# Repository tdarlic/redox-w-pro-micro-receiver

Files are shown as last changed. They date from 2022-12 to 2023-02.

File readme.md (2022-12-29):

# [Redox](https://github.com/mattdibi/redox-keyboard) W Pro Micro receiver

The original Redox keyboard is using receiver that consists from the Arduino Pro Micro board and custom made "shield"
that is used to put few leds and a YJ-14015 module (Core51822B clone).

This PCB uses the on board copper connection to plug directly into the computer.
 
The rest of the board can be used the same way, there is a programming port for YJ-14015 module.

## Versions

### Full version [main branch]
This is single sided PCB with few test pads on the bottom
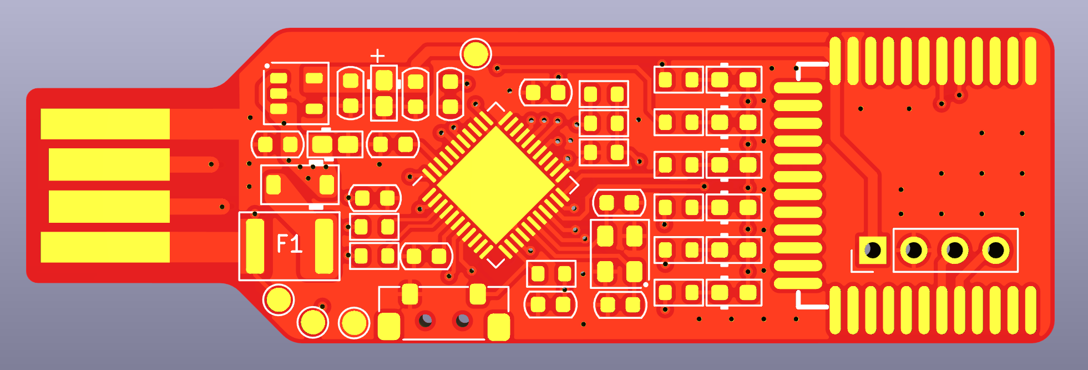
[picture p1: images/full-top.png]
Full board top side

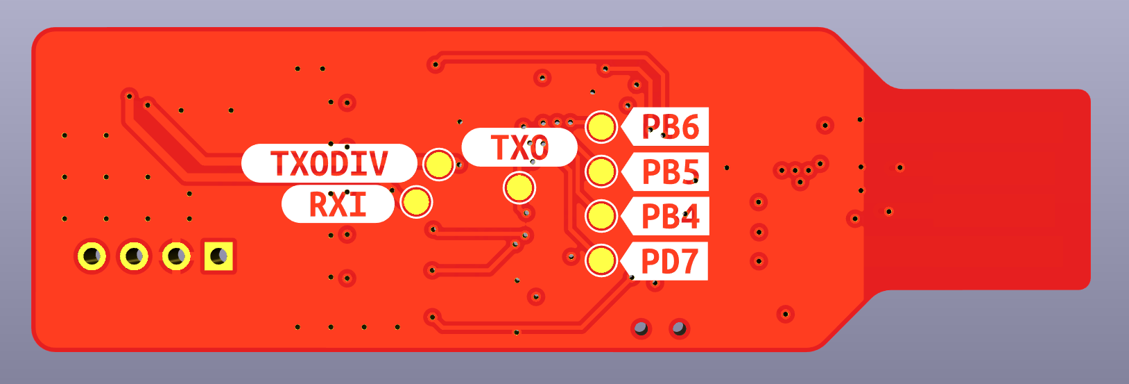
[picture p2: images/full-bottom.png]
Full board bottom side


### Mini version [mini branch]
This is double sided PCB with YJ-14015 on the bottom together with some test pads
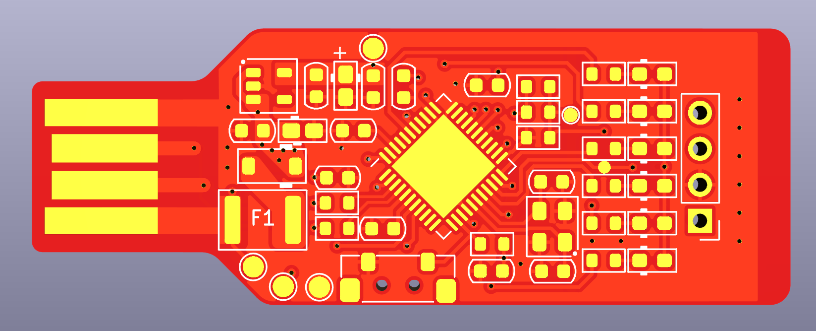
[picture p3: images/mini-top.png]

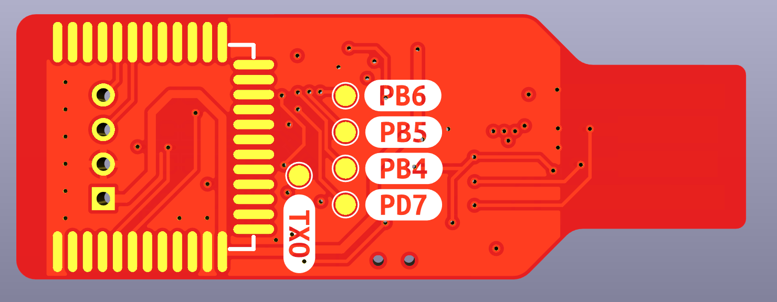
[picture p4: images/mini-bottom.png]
Full board bottom side


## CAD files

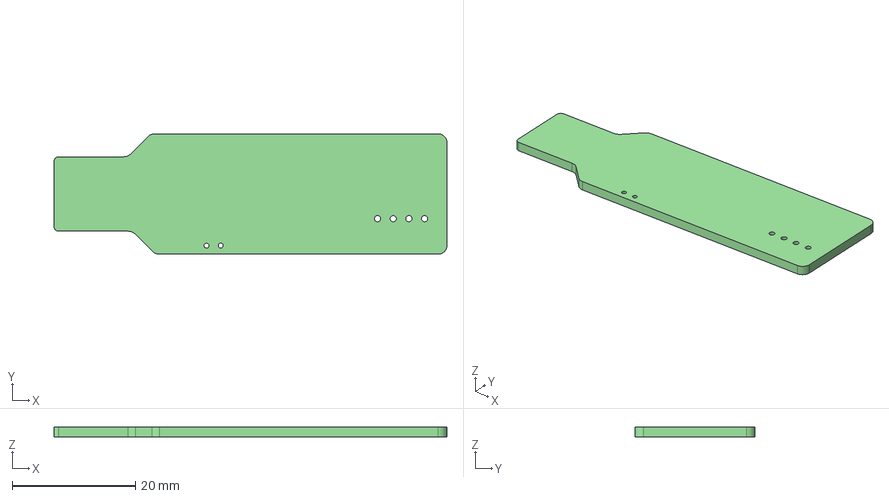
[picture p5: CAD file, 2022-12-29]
3d/pro-micro-receiver.step
63.7 x 19.5 x 1.61 mm

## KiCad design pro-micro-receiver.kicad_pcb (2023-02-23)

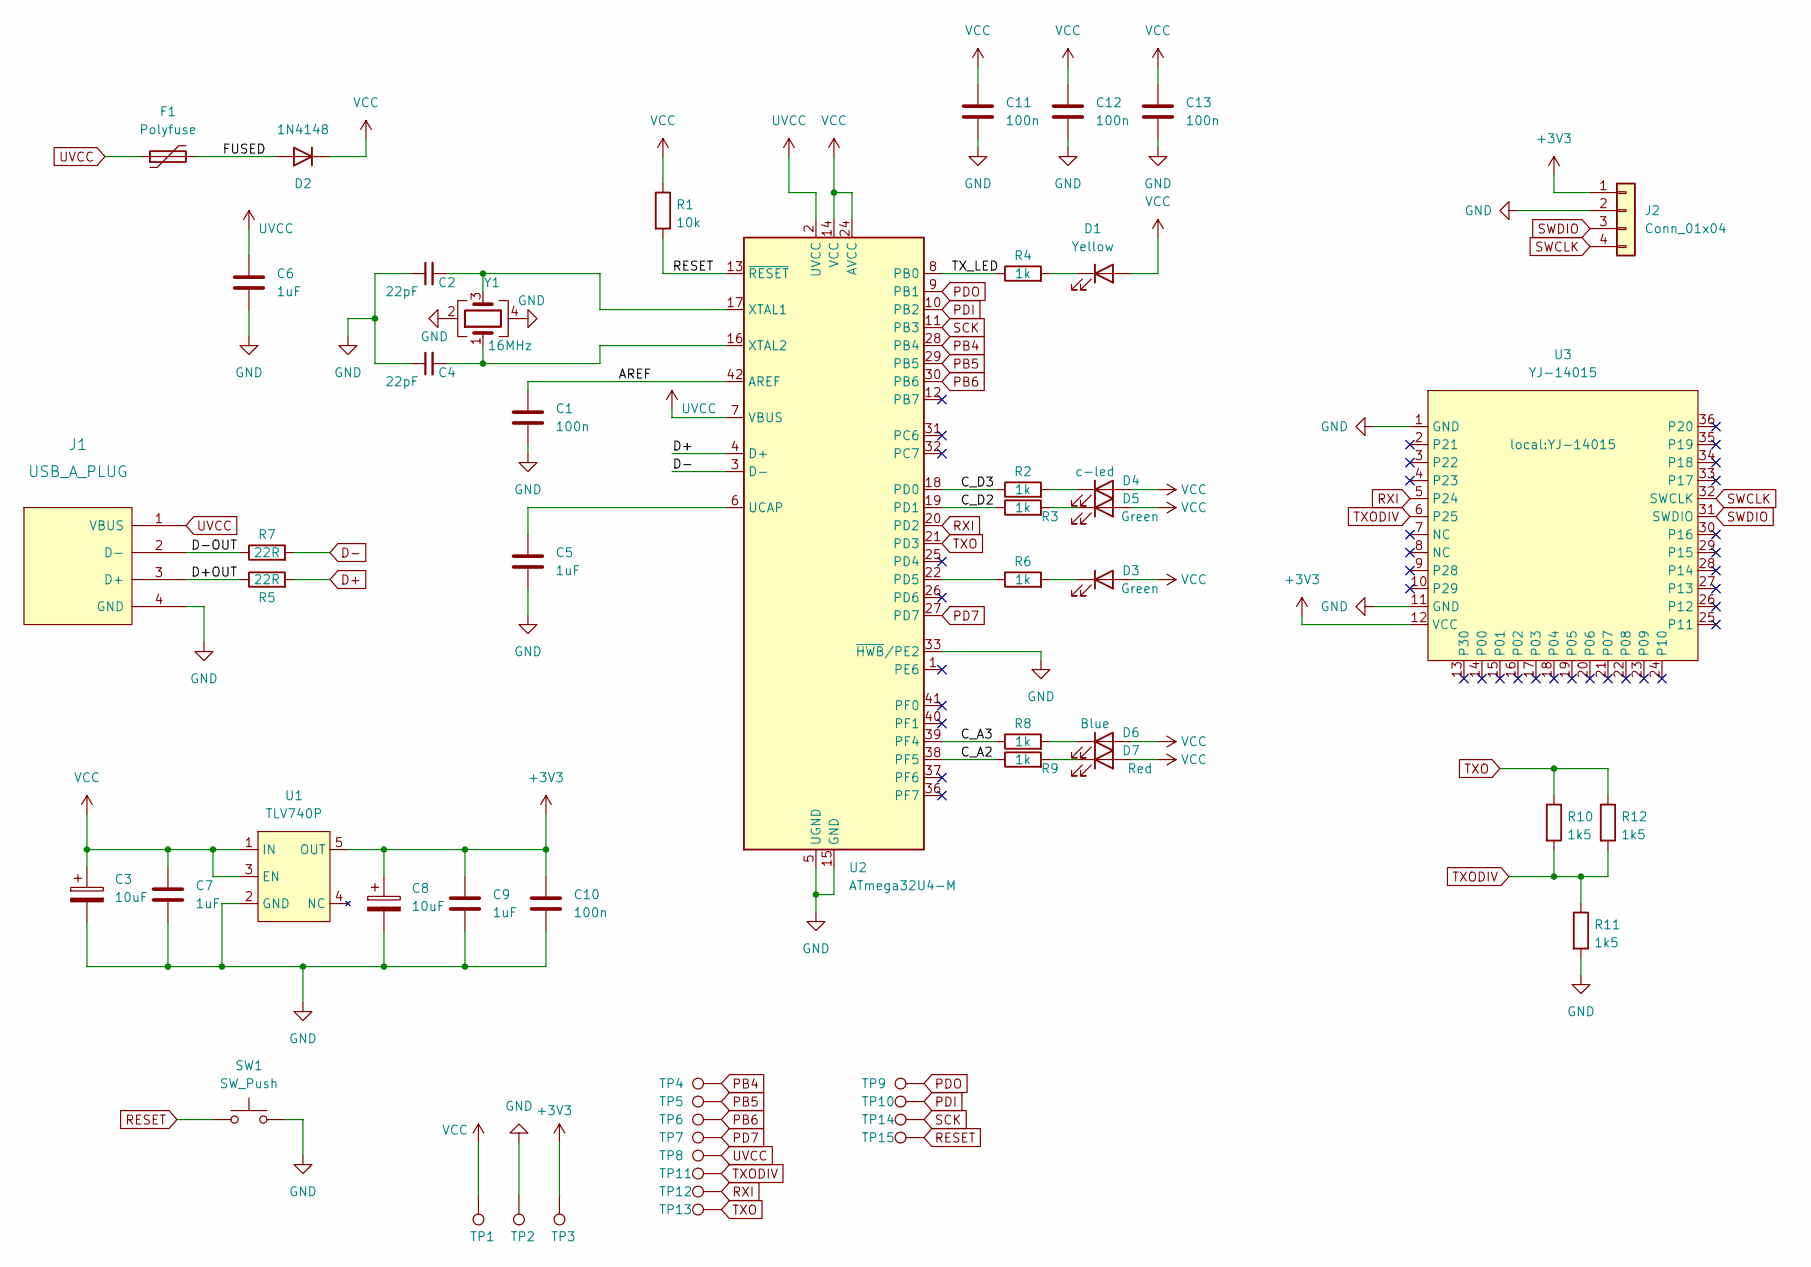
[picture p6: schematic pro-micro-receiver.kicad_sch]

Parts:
C1, C10, C11, C12, C13: 100n; C_0603_1608Metric
C2, C4: 22pF; C_0603_1608Metric
C3, C8: 10uF; CP_EIA-1608-10_AVX-L_Pad1.25x1.05mm
C5, C6, C7, C9: 1uF; C_0603_1608Metric
D1: Yellow; D_0603_1608Metric_Pad1.05x0.95mm
D2: 1N4148; D_SOD-123
D3, D5: Green; D_0603_1608Metric_Pad1.05x0.95mm
D4: c-led; D_0603_1608Metric_Pad1.05x0.95mm
D6: Blue; D_0603_1608Metric_Pad1.05x0.95mm
D7: Red; D_0603_1608Metric_Pad1.05x0.95mm
F1: Polyfuse; Fuse_1812_4532Metric
J1: USB_A_PLUG; usb-PCB
J2: Conn_01x04; PinHeader_1x04_P2.54mm_Vertical
R1: 10k; R_0603_1608Metric
R2, R3, R4, R6, R8, R9: 1k; R_0603_1608Metric
R5, R7: 22R; R_0603_1608Metric
R10, R11, R12: 1k5; R_0603_1608Metric
SW1: SW_Push; BZCN_TSB001A3512A
TP1, TP2, TP3, TP4, TP5, TP6, TP7, TP8, TP9, TP10, TP11, TP12, TP13, TP14, TP15: TestPoint; TestPoint_Pad_D1.5mm
U1: TLV740P; SOT-23-5
U2: ATmega32U4-M; QFN-44-1EP_7x7mm_P0.5mm_EP5.2x5.2mm
U3: YJ-14015
Y1: 16MHz; Crystal_SMD_EuroQuartz_MT-4Pin_3.2x2.5mm

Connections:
+3V3: C8.1, C9.1, C10.1, J2.1, TP3.1, U1.5 (OUT), U3.12 (VCC)
/AREF: C1.1, U2.42 (AREF)
/C_A2: R9.1, U2.38 (PF5)
/C_A3: R8.1, U2.39 (PF4)
/C_D2: R3.1, U2.19 (PD1)
/C_D3: R2.1, U2.18 (PD0)
/D+OUT: J1.3 (D+), R5.1
/D-OUT: J1.2 (D-), R7.1
/FUSED: D2.2 (A), F1.2
/TX_LED: R4.1, U2.8 (PB0)
D+: R5.2, U2.4 (D+)
D-: R7.2, U2.3 (D-)
GND: C1.2, C2.1, C3.2, C4.1, C5.2, C6.2, C7.2, C8.2, C9.2, C10.2, C11.2, C12.2, C13.2, J1.4 (GND), J2.2, R11.2, SW1.2, TP2.1, U1.2 (GND), U2.5 (UGND), U2.15 (GND), U2.23 (GND), U2.33 (~HWB/PE2), U2.35 (GND), U2.43 (GND), U2.45 (GND), U3.1 (GND), U3.11 (GND), Y1.2, Y1.4
unnamed: C2.2, U2.17 (XTAL1), Y1.3
unnamed: C4.2, U2.16 (XTAL2), Y1.1
unnamed: C5.1, U2.6 (UCAP)
unnamed: D1.1 (K), R4.2
unnamed: D3.1 (K), R6.2
unnamed: D4.1 (K), R2.2
unnamed: D5.1 (K), R3.2
unnamed: D6.1 (K), R8.2
unnamed: D7.1 (K), R9.2
unnamed: R6.1, U2.22 (PD5)
PB4: TP4.1, U2.28 (PB4)
PB5: TP5.1, U2.29 (PB5)
PB6: TP6.1, U2.30 (PB6)
PD7: TP7.1, U2.27 (PD7)
PDI: TP10.1, U2.10 (PB2)
PDO: TP9.1, U2.9 (PB1)
RESET: R1.2, SW1.1, TP15.1, U2.13 (~RESET)
RXI: TP12.1, U2.20 (PD2), U3.5 (P24)
SCK: TP14.1, U2.11 (PB3)
SWCLK: J2.4, U3.32 (SWCLK)
SWDIO: J2.3, U3.31 (SWDIO)
TXO: R10.1, R12.1, TP13.1, U2.21 (PD3)
TXODIV: R10.2, R11.1, R12.2, TP11.1, U3.6 (P25)
UVCC: C6.1, F1.1, J1.1 (VBUS), TP8.1, U2.2 (UVCC), U2.7 (VBUS)
VCC: C3.1, C7.1, C11.1, C12.1, C13.1, D1.2 (A), D2.1 (K), D3.2 (A), D4.2 (A), D5.2 (A), D6.2 (A), D7.2 (A), R1.1, TP1.1, U1.1 (IN), U1.3 (EN), U2.14 (VCC), U2.24 (AVCC), U2.34 (VCC), U2.44 (AVCC)

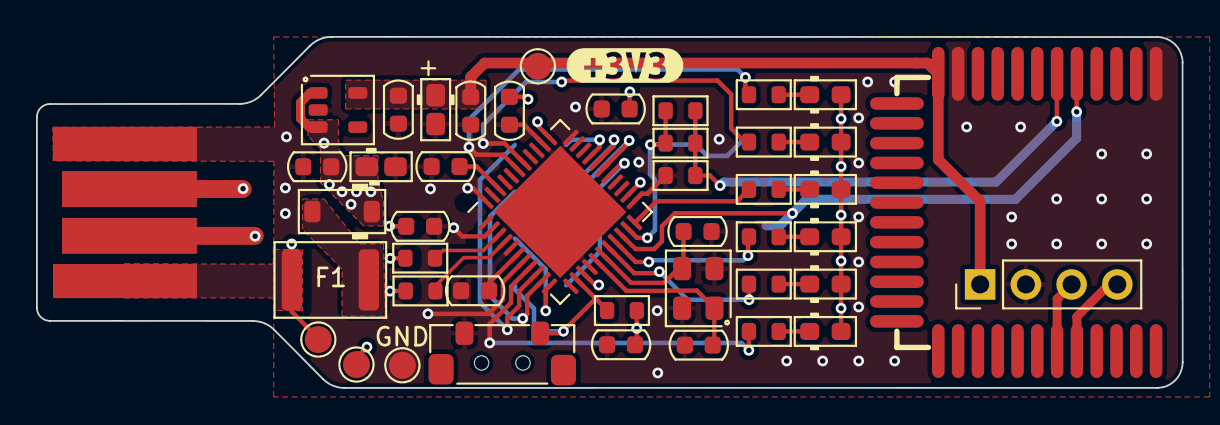
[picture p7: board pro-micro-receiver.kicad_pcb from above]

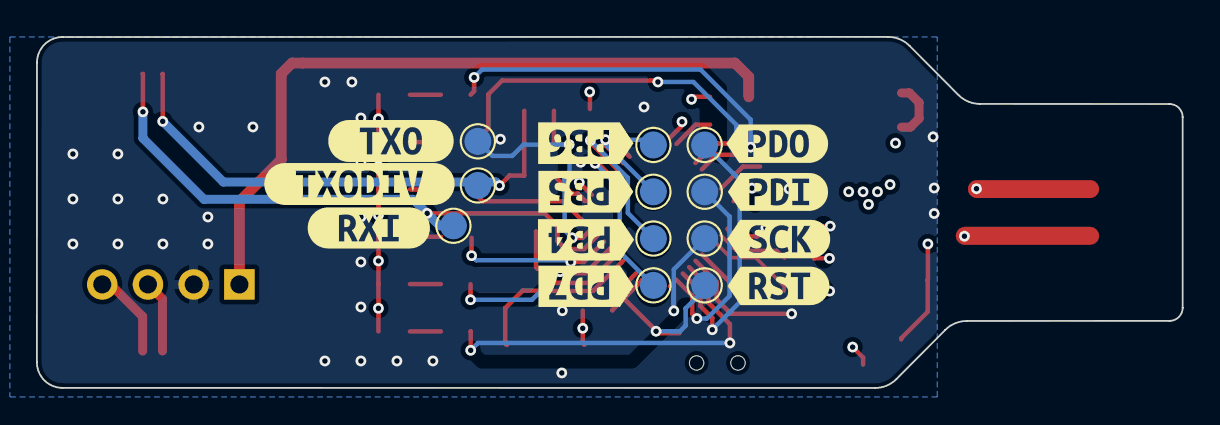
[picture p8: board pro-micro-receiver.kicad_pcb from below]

Board: 4 copper layers, 63.7 x 19.5 mm, 67 parts (22 on the bottom side), 38 nets.

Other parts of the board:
kibuzzard-63ACD5DB: G***; kibuzzard-63ACD5DB
kibuzzard-63ACD5FF: G***; kibuzzard-63ACD5FF
kibuzzard-63ACD69E: G***; kibuzzard-63ACD69E
kibuzzard-63ACD615: G***; kibuzzard-63ACD615
kibuzzard-63ACD627: G***; kibuzzard-63ACD627
kibuzzard-63ACD667: G***; kibuzzard-63ACD667
kibuzzard-63ACD680: G***; kibuzzard-63ACD680
kibuzzard-63BC8742: G***; kibuzzard-63BC8742
kibuzzard-63F7D9D7: G***; kibuzzard-63F7D9D7
kibuzzard-63F7D9F1: G***; kibuzzard-63F7D9F1
kibuzzard-63F7DA1C: G***; kibuzzard-63F7DA1C
kibuzzard-63F7DA07: G***; kibuzzard-63F7DA07

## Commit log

2022-12-27 Adding existing files to a project - initial commit
    [pro-micro-receiver.kicad_pcb, pro-micro-receiver.kicad_sch]
2022-12-27 Fixing the stackup Adding initial board outline Moving all elements onto the board
    [pro-micro-receiver.kicad_pcb, pro-micro-receiver.kicad_sch]
2022-12-27 Shortening the board and better placement of components
    [pro-micro-receiver.kicad_pcb]
2022-12-28 Compacting the board
    Shifting the crystal and the components to shorten the board
    Distancing the elements from the edge
    Rounding the corners
    [pro-micro-receiver.kicad_pcb]
2022-12-28 Completed routing board
    Removed all designators from silkscreen
    [pro-micro-receiver.kicad_pcb, pro-micro-receiver.kicad_sch]
2022-12-28 Adding testpoints in schematic
    [pro-micro-receiver.kicad_sch]
2022-12-28 Adding testpoints to PCB
    [pro-micro-receiver.kicad_pcb, pro-micro-receiver.kicad_sch]
2022-12-28 Adding flags for testpoints
    [pro-micro-receiver.kicad_pcb]
2022-12-29 Small fixes on the PCB
    [pro-micro-receiver.kicad_pcb, pro-micro-receiver.step]
2022-12-29 Adding missing resistor values
    [pro-micro-receiver.kicad_sch]
2023-01-09 Adding labels to +3V3 and GND testpoints
    [pro-micro-receiver.kicad_pcb]
2023-02-23 Adding BOM for assembly and programming port on the back
    [pro-micro-receiver.kicad_pcb, pro-micro-receiver.kicad_sch]
